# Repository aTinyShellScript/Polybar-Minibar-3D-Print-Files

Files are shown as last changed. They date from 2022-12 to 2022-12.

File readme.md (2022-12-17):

# A Tiny Mod

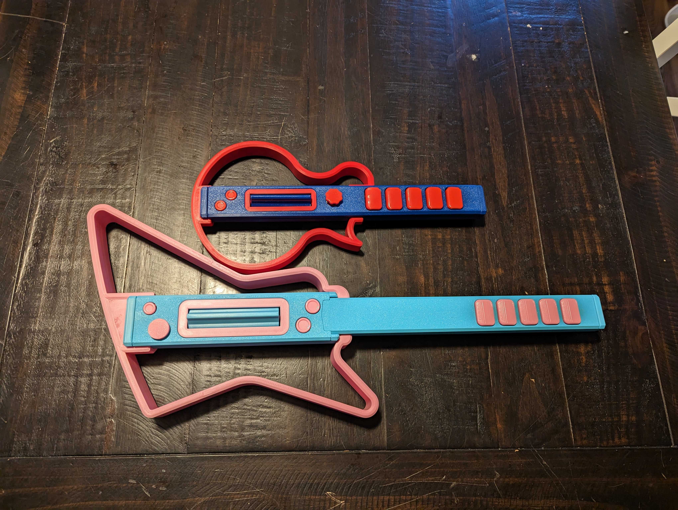
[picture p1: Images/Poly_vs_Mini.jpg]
Size Comparison


## Full BOM

The PolyBar and MiniBar use 99% the same BOM but the MiniBar uses 1 less microswitch and 1 less M5 heatset.

- Filament (200-250g or so)
- 1x Raspberry Pi Pico or Clone
    - WaveShare 2040-Plus recommended for USB-C (https://www.amazon.com/gp/product/B09LT4V2VS)
    - OG Pico https://www.amazon.com/dp/B08W3SH4TD
- 7x Cherry MX Keyboard Switches
    - https://www.amazon.com/dp/B07X3TH4DS
- 1x Arduino Joystick Module
    - https://www.amazon.com/gp/product/B014KQLE8Q
- 3x M5 HeatSet Insert
    - https://www.amazon.com/dp/B08T9W17CR
- 3x 6x6x4.5mm Momentary Switch
    - https://www.amazon.com/dp/B01N6GU7TA
- 3x M5x20mm Hex Head Bolts
    - https://www.amazon.com/dp/B01N6GU7TA
- 1x M5x30mm Hex Head Bolt
    - This is for my modded guitar bodies, to hold the outer frame on. It replaces one of the 20mms
- 2x Metal Ball Tile Sensors
    - https://www.amazon.com/dp/B00RGN0KY0

# Changes

## BOM Changes for PolyBar

- 1x M3 heatset
- 1x M3x8mm bolt

## File Changes

### Neck

#### Changes
- M5 heatset holes tightened up. Were too loose stock.
- Removed dovetail from the Neck Top and added an bit that overlaps Strum Case Top to hold everything tight once assembled. The top of the neck should be the last thing installed now.
- Added hole at the base of the neck for an M3 bolt to allow easy attaching to Strum Case Bottom.
- Lowered Fret_Switches_Board 1mm to work well with the keyboard switches I bought.
#### Combined

- Extension Case Top and Fret Case Top were combined into PB_Fret_Extension_Top_OnePiece.
- Extension Case Bottom and Fret Case Bottom were combined into PB_Fret_Extension_Bottom_OnePiece.

### Strum Case

#### Changes
- Strum Case Bottom had a hole added for an M3 heatset for attaching the Neck Bottom.
- Strum Case Bottom had holes added for usb-c extension cable mounting. https://www.amazon.com/dp/B08HS6X44P
- Strum Case Top had a void added where the Neck Top fits in to hold it in place.
- Strum Case Top had the face plate hole deepened by 1mm for reasons unknown.
- Face Plate thiccened by 1mm.
### Interior Bits

#### Changes
- Spot added to ButtonBoard to hot glue your tilt switches in place.
- Removed lip, added holes, and removed overhangs on Joystick_Board

### Frame

#### Changes
- Combined the two pieces into one piece
- Removed lip at front where it slotted into the neck.
- Added hole for M5 bolt to allow solid attachment to neck.
- Made a big ass slot to make it easier to attach your usb-c cable.

## Pico Wiring

TL;DR - Not done yet.

Get the guitar configurator here: https://github.com/sanjay900/guitar-configurator/releases

MAKE SURE YOU WIRE THE JOYSTICK X AND Y INTO PINS 31 and 32!!!

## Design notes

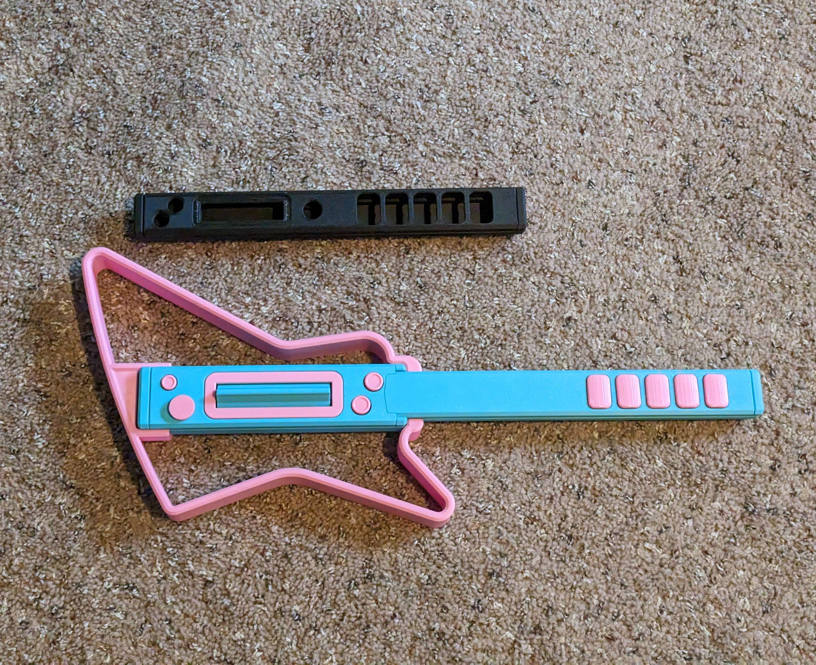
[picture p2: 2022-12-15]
Images/comparison.jpg

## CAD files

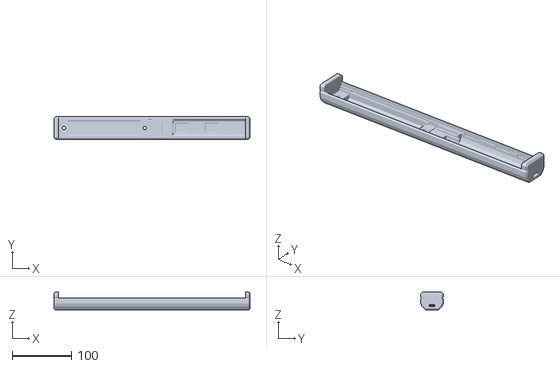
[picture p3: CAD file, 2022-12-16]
Mods/MiniBar/MB_Case_Bottom.stl
331.0 x 38.0 x 30.0

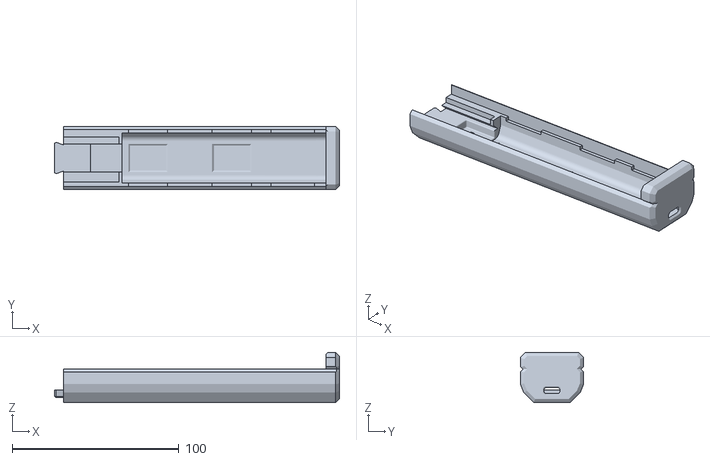
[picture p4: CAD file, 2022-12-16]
Mods/MiniBar/Small Bed Alternates/MB_Strum_Case_Bottom.stl
170.9 x 38.0 x 30.0

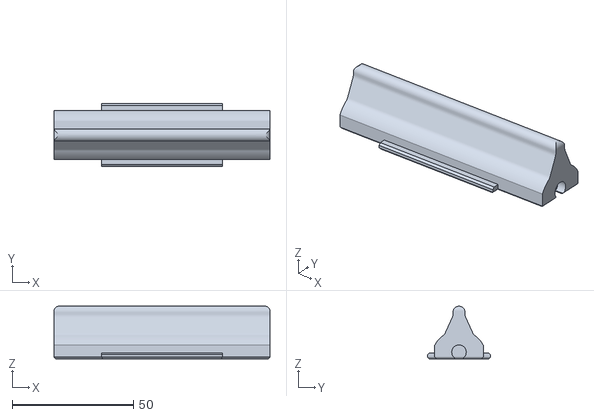
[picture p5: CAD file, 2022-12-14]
Mods/PolyBar/[a]PB_Strum_Bar.stl
89.0 x 26.0 x 21.7

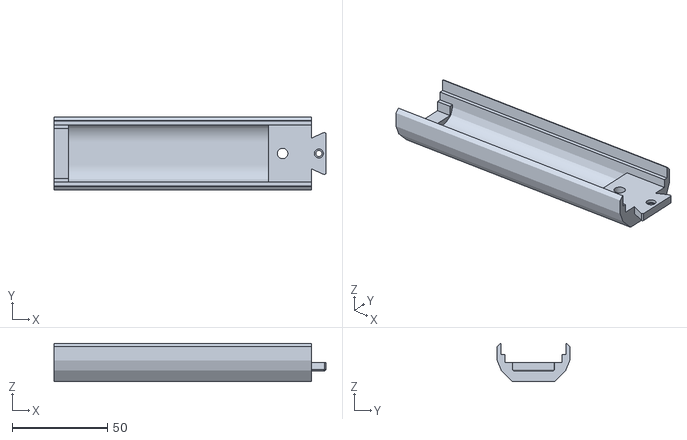
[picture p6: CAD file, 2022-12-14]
Mods/PolyBar/Small Bed Alternates/PB_Extension_Case_Bottom.stl
142.5 x 38.0 x 20.0

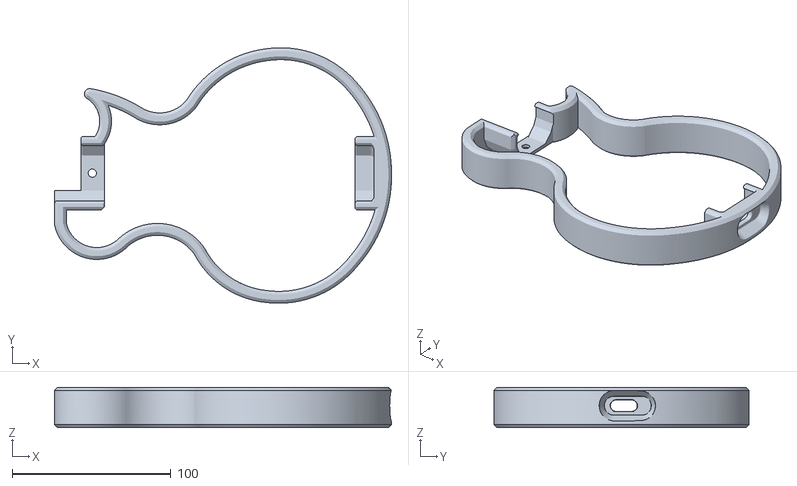
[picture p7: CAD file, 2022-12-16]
Mods/MiniBar/[a]Les_Paul_Frame.stl
212.5 x 161.1 x 25.5

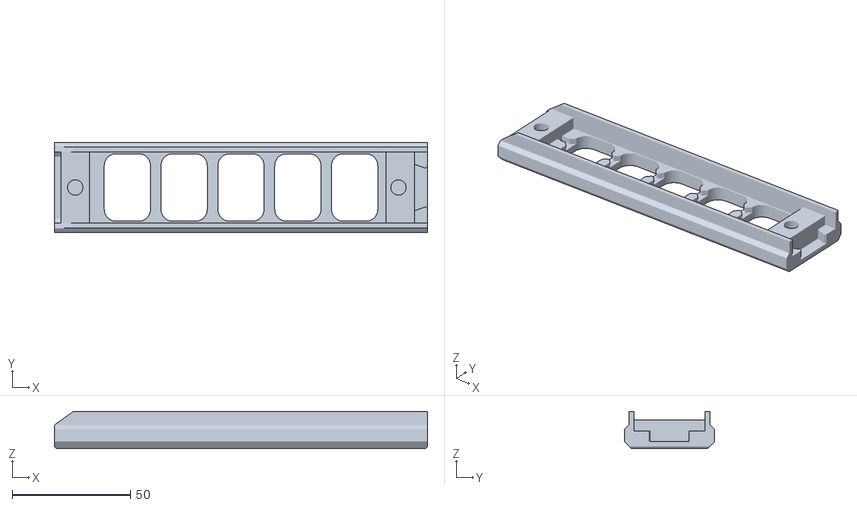
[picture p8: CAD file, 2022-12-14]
Mods/MiniBar/Small Bed Alternates/MB_Fret_Case_Top.stl
157.5 x 38.0 x 15.8

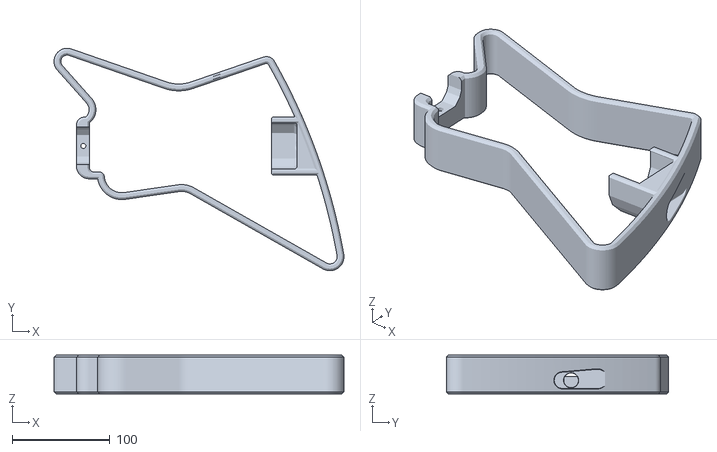
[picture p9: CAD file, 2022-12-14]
Mods/PolyBar/[a]Polybar_Xplorer_Frame_One_Piece.stl
296.3 x 227.3 x 39.4

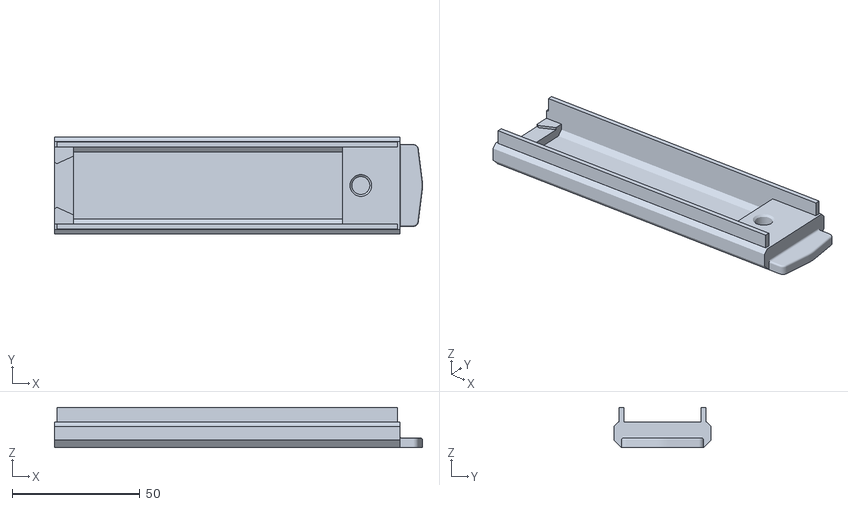
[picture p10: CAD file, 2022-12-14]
Mods/PolyBar/Small Bed Alternates/PB_Extension_Case_Top.stl
143.8 x 38.0 x 15.7

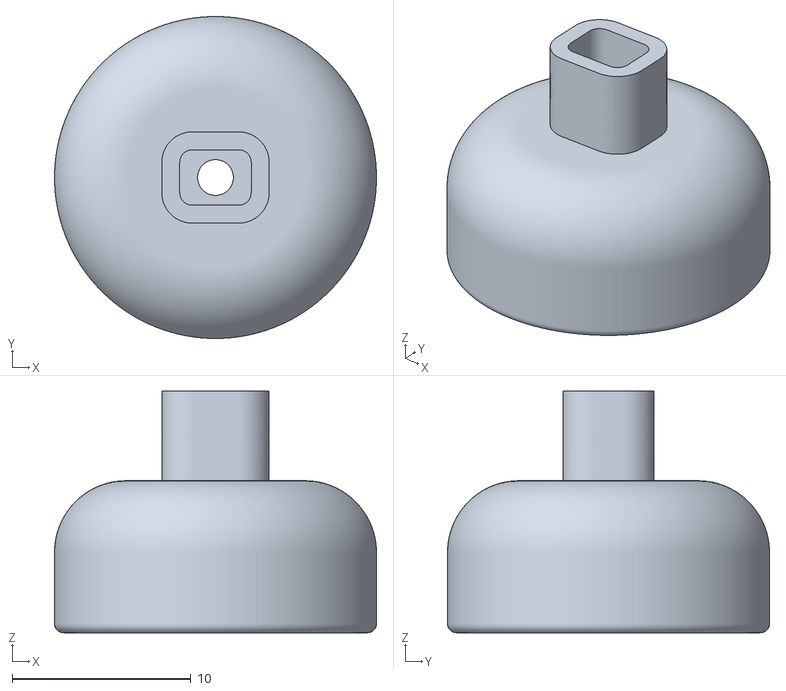
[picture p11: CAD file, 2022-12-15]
Mods/MiniBar/[a]Whammy_Mount_2mm.stl
18.0 x 18.0 x 13.5

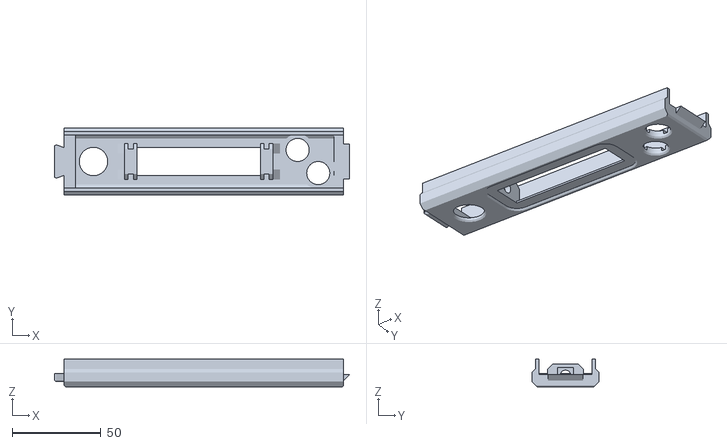
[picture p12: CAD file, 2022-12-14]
Mods/MiniBar/Small Bed Alternates/MB_Strum_Case_Top.stl
166.2 x 38.0 x 15.8

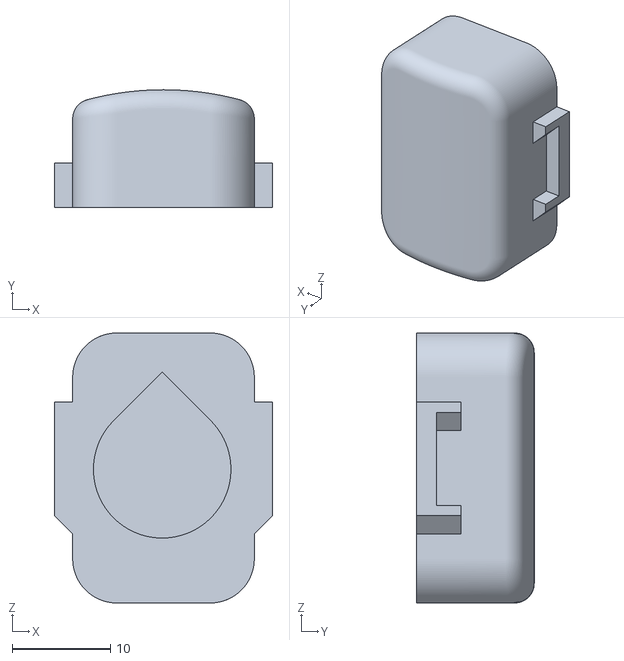
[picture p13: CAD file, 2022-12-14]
Mods/PolyBar/[a]Fret_[x5].stl
22.2 x 12.0 x 27.5

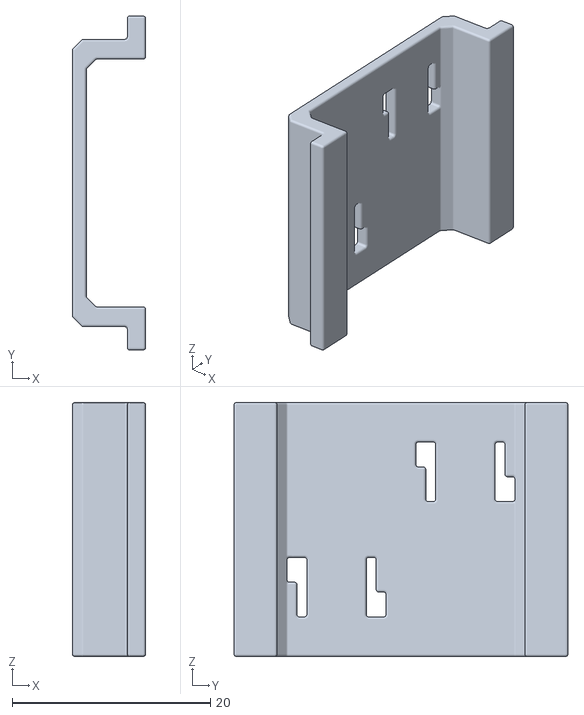
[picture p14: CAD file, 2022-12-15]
Mods/MiniBar/[a]MB_Button_Board.stl
7.38 x 33.7 x 25.6

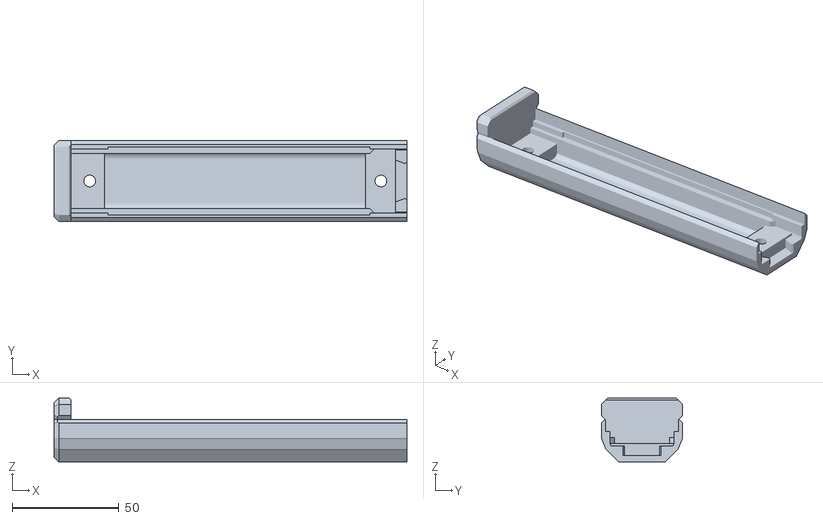
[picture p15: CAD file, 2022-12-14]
Mods/MiniBar/Small Bed Alternates/MB_Fret_Case_Bottom.stl
165.5 x 38.0 x 30.0

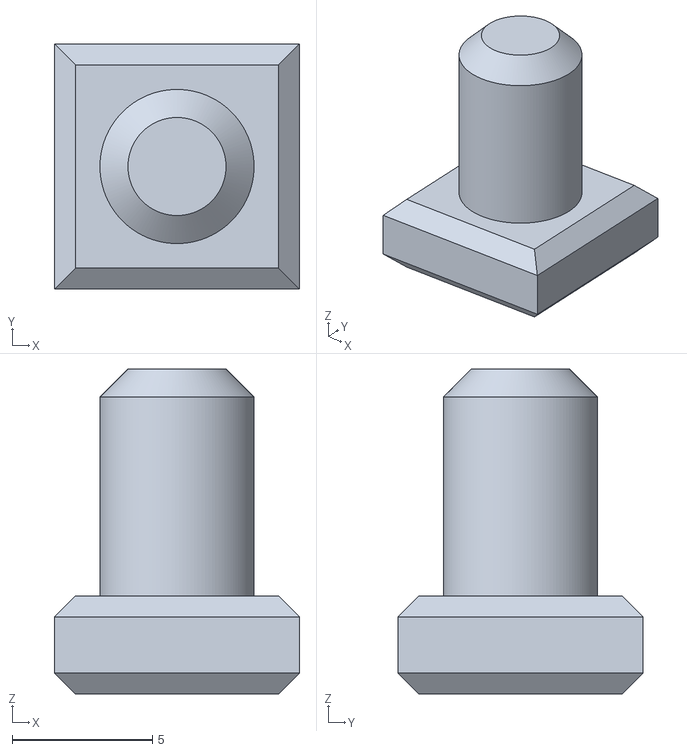
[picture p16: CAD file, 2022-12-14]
Mods/PolyBar/[a]Strumbar_Swivel_[x2].stl
8.75 x 8.75 x 11.6

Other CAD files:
Mods/PolyBar/Small Bed Alternates/PB_Fret_Case_Top.stl
Mods/PolyBar/Small Bed Alternates/PB_Fret_Case_Bottom.stl
Mods/MiniBar/[a]MB_Face_Plate.stl
Mods/PolyBar/[a]PB_Button_Board.stl
Mods/MiniBar/MB_Case_Top.stl
Mods/MiniBar/MB_Strum_Bar.stl
Mods/MiniBar/[a]Board_Fret_Switches.stl
Mods/MiniBar/[a]Fret_Mount_Insert_[x5].stl
Mods/MiniBar/[a]Joystick_Cap.stl
Mods/MiniBar/[a]MB_Button_Board_Original_Height.stl
Mods/MiniBar/[a]MB_Small_Button_[x2].stl
Mods/MiniBar/[a]MB_Strum_Board_[x2].stl
Mods/MiniBar/[a]Strum_Switch_Insert_[x2].stl
Mods/MiniBar/[a]Strum_Swivel_Retainer_[x2].stl
Mods/PolyBar/PB_Fret_Extension_Bottom_SinglePiece.stl
Mods/PolyBar/PB_Fret_Extension_Top_SinglePiece.stl
Mods/PolyBar/PB_Strum_Case_Bottom.stl
Mods/PolyBar/PB_Strum_Case_Top.stl
Mods/PolyBar/[a]Fret_Mount_Insert_[x5].stl
Mods/PolyBar/[a]Fret_Switches_Board.stl
Mods/PolyBar/[a]Joystick_Cap.stl
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

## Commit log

2022-12-14 initial commit
    All my changed stls and f3d file.
    [PB_Extension_Case_Bottom.stl, PB_Extension_Case_Top.stl, PB_Fret_Case_Bottom.stl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]
2022-12-14 ReOrg
    Added MiniBar and moved PolyBar to own folder
    [MB_Case_Bottom.stl, MB_Case_Top.stl, MB_Fret_Case_Bottom.stl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]
2022-12-15 Added full BOM
    [[a]Les_Paul_Frame.stl]
2022-12-15 Update Polybar v4.4 - atss edition.f3d
    [Polybar v4.4 - atss edition.f3d]
2022-12-15 Fixes
    Button height and frame fixes.
    [Polybar v4.4 - atss edition.f3d, [a]Les_Paul_Frame.stl, [a]MB_Button_Board.stl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]
2022-12-16 Raised Cable Hole for MB Les Paul
    Was too low. Looks wrong in CAD now but prints right. ??? Confusing.
    [Polybar v4.4 - atss edition.f3d, [a]Les_Paul_Frame.stl]
2022-12-16 Minibar Pico Clearancing
    MiniBar didn't have clearance to fit a Raspberry Pi Pico. Now it does.
    [MB_Case_Bottom.stl, MB_Strum_Case_Bottom.stl, Polybar v4.4 - atss edition.f3d]
